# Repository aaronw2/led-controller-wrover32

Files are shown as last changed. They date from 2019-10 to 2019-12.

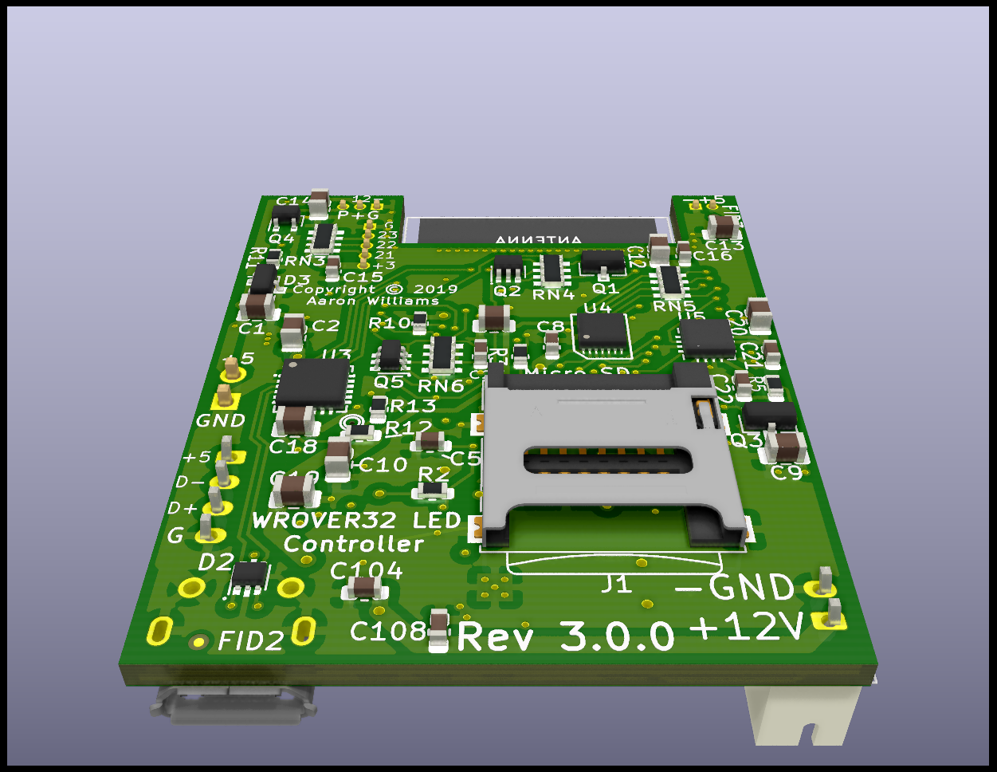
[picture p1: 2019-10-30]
led-controller-wrover32/Pictures/Back-angle.png

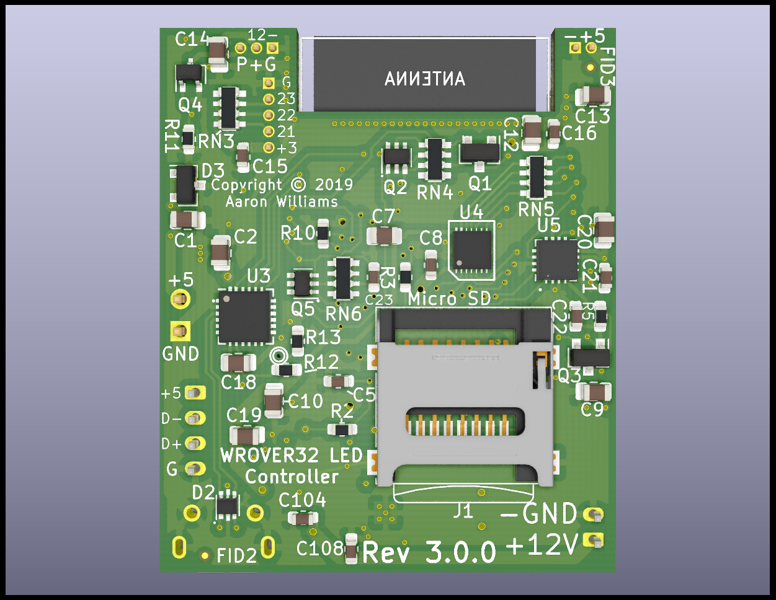
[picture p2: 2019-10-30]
led-controller-wrover32/Pictures/Back.png

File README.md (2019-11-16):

# led-controller-wrover32
Wrover32 based LED controller for NeoPixels and DotStars with 5v signalling
and micro SD

Power:

This board is powered by 5V and generates a 3.3V supply via U1.  This board
may draw up to 500ma of current at 5V.  The 3.3V supply is capable of
generating up to 1A.

This board makes use of a Torex Semiconductor XCL220 micro DC/DC converter
to efficiently provide 3.3v of power.  This inexpensive device is reportedly
93% efficient which should increase battery life and reduce heat buildup.

Do not draw more than 500ma from any single power or ground pin on J2 or J4.

On J5, VBUS is 5V as are pins 9 and 12 on J4 and pin 1 on J2.
J6 and J7 also provide +5V at the + terminal.

5V may be shunted through the board, but limit the current to no more than 2A.

5V may be supplied by any pin, however power provided by the micro SD
connector J3 should be limited to 500 ma.

USB:

There are two USB connectors on the board for programming.  The Micro USB
connector J3 or J5 may be used.  Do not use both connectors.  J5 is designed
so either a 4 pin header or a USB cable can be soldered to the board,
eliminating the need to use micro USB.

The USB port is connected to a SI Labs CP2102 USB to serial UART for
programming and debugging purposes.

I/O:

Unlike most if not all other ESP32 based boards, this board includes a
3V to 5V bidirectional level shifter for IO25, IO26, IO32 and IO33.  These
I/O ports can also be driven by the RTC in the ESP32 to help offload driving
NeoPixels.

I/O27 is connected to an on-board SK6812MINI RGB NeoPixel with the output
connected to J2 pin 4.

Connectors:

J1: Micro SD connector

J2:
1 - VBUS (+5V)
2 - GND
3 - +3.3V
4 - DO - Output from on-board NeoPixel
5 - IO34
6 - IO33_H - IO33 at 5v signalling
7 - IO32_H - IO32 at 5V signalling
8 - IO18_H - IO18 at 5V signalling
9 - IO5_H - IO5 at 5V signalling
10 - SENSOR_VN - Input to Sensor_VN pin
11 - SENSOR_VP - Input to Sensor_VP pin
12 - Reset

J3: Micro USB connector

J4:
1 - IO23 (10K pullup)
2 - IO22 (10K pullup)
3 - IO21 (10K pullup)
4 - IO19
5 - IO26
6 - IO25
7 - IO35
8 - IO0
9 - +3.3V
10 - GND
11 - GND
12 - VBUS (+5V)

J5: USB
1 - VBUS (+5) (3A input capable)
2 - D-
3 - D+
4 - GND

J6:
1 - GND
2 - VBUS (+5V)

J7:
1 - GND
2 - VBUS (+5V)
3 - FET connected to ground, driven by IO26 (max 1A, 12V)

J8:
1 - GND
2 - IO23 (pullup) same as J4-1
3 - IO22 (pullup) same as J4-2
4 - IO21 (pullup) same as J4-3
5 - +3.3V

J9:
1 - GND
2 - +5V (3A input capable)

J11:
1 - Speaker +
2 - Speaker -

J101:
Note: pins 1 and 2 are the opposite of other power connectors
1 - +12V 400ma
2 - GND

I2C:
I2C is supported on pins IO21, IO22 and IO23, though one of those pins can
also be used for a shared interruput line.

Notes:
Some pins serve multiple purposes.  For example, two of the 5V I/O pins are
shared.  For example, IO5 is also connected to the FET for PWM and IO33 is
also connected to the BCLK on the amplifier.  If these are used, do not use
the 5V I/Os for IO5 and/or IO33.  If IO33 is used, do not hook up a speaker.

IO18 and IO32 are dedicated for 5V I/O and IO27 is dedicated for the status
LED and the output of that is useable for driving WS2812s or compatible 24-bit
LEDs.

Power:

This board uses a Torex Semiconductor XCL220 buck converter to efficiently
generate 3.3v with an output capability of up to 1A.  It supports automatic
shutdown for thermal, overcurrent and under voltage events.

Any VBUS (+5V) pin many be used to deliver or draw 5V from the board.  Total
current should not exceed 2A for all combined ground and +5V pins, however
for power input connectors J5 and J9 are capable of handling 3A in order to
supply the 12V booster

Ground:
Any GND pin can be used for ground.

+3.3V
The on-board power supply is capable of generating up to 1A.  The Wrover32 can
consume up to 500ma.  Please limit power consumption to no more than 200ma to
be safe.

+12V
This board includes a 5V to 12V boost circuit in order to provide power to
a fan or other accessories via J101.  Do not exceed 400ma.  All components
needed for the 12V boost circuit start at reference 100.  To disable 12V
support, do not install any components in this range, i.e. J101, R101, etc.

RESET:

This board can be reset in one of three ways.  The serial UART, SW1 and J2
pin 12 can all be used to reset the board.  To reset the board using J2,
pull the RESET line to ground.

5V logic

This board is designed to be able to drive 5 channels of NeoPixels, or two
channels of DotStars and one channel of NeoPixels.  One NeoPixel (D1) is
built-in to the board and the output is connected to J2 pin 4.  The other
four channels are pins J2 6, 7, 8 and 9.  Note that D1 uses a WS2813B-Mini.

Connectors J2 and J4:

Connectors J2 and J4 and JST VM12B-SRSS-TB connectors and mate with the
JST 12SR-3S connector.  These connectors can be found at Digikey, including
connectors with wires already installed. Note that the wire for the mating
connectors is a bit hard to find. Alpha Wire 2928 WH005 fits this connector.
It is a bit pricy. Mouser has it cheaper than Digikey for $35/100 feet,
though I also found it online for $25. The connector requires 7 strand wire
with an outer diameter between 0.54 and 0.58mm.

Connectors J5 and J101 are JST PH series connectors which are readily
available. J101 is not at all uncommon for computer fans.

All other connectors are pin headers with 1.27mm pitch, which is half the
normal 2.54mm pitch except for J9, which uses the 2.54mm pitch.

USB:
Use either a micro USB cable OR J5, do not use both for USB I/O.  Both,
however, are safe for power and ground, however do not exceed 900ma
when using a micro USB cable.

Microphone:

An optional SPH0645LM4H-B i2s compatible microphone is available.
If present, it is configured for the left channel.  Word-select is on IO5,
clock is on IO0 and data is on IO35.

Fan control:
The PWM pin is not near the 12v supply due to routing issues.  In order to
use PWM support, the fan must be connected to +12 or +5 and the PWM pin
(J7 pin 3) for ground. Note that J7 pin 3 should never be shorted to ground
as this will cause Q4 to act as a diode and likely burn up.

Booting and programming:
This follows the model used on the Wrover development board where DTR and
RTS are used to control IO0, IO2 and RESET.  Note that revision 1.5 and later
fixes the programming by supporting IO2.  IO2 is new for the Wrover32 and is
not used by the Wroom32.

GPIOs:
IO0: I2S-BCLK, RTS for programming, J4-8
IO2: SD-DAT0, RTS for programming
IO4: SD-DAT1
IO5: 5V I/O, FAN PWM
IO12: SD-DAT2
IO13: SD-DAT3/CD
IO14: SD-Clock
IO15: SD-Command
IO16: do not use
IO17: do not use
IO18: 5V I/O
IO19: mic I2S-WS, JU4-4
IO21: Pull-up, J4-3, SDA
IO22: Pull-up, J4-2, SCL
IO23: Pull-up, J4-1, /INT
IO25: J4-6, Speaker DIN
IO26: J4-5, Speaker BCLK
IO27: Status RGB LED output
IO32: 5V I/O
IO33: 5V I/O, Speaker LRCLK
IO34: J2-5 (input only)
IO35: MIC I2S-data in, J4-7
SENSOR_VP: J2-11
SENSOR_VN: J2-10

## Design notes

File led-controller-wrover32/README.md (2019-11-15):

ESP32-Wrover I/Os

IO0: (reset/program), J4-8, MIC-BCLK
IO2: (reset/program), SD DAT0
IO4: SD DAT1
IO5: +5V I/O, FAN PWM
IO12: SD DAT2
IO13: SD DAT3/CD
IO14: SD CLK
IO15: SD CMD
IO16: DNC
IO17: DNC
IO18: +5V I/O
IO19: J4-4, MIC WS
IO21: I2C/INT, J4-3
IO22: I2C/INT, J4-2
IO23: I2C/INT, J4-1
IO25: J4-6, SPKR-DIN
IO26: J4-5, SPKR-BCLK
IO27: NeoPixel
IO32: +5V
IO33: +5V, SPKR-LRCLK
IO34: (input only) J2-5
IO35: (input only) J4-7, MIC-OUT
SENSOR_VP: J2-11
SENSOR_VN: J2-10
RXD0:
TXD0:
EN:

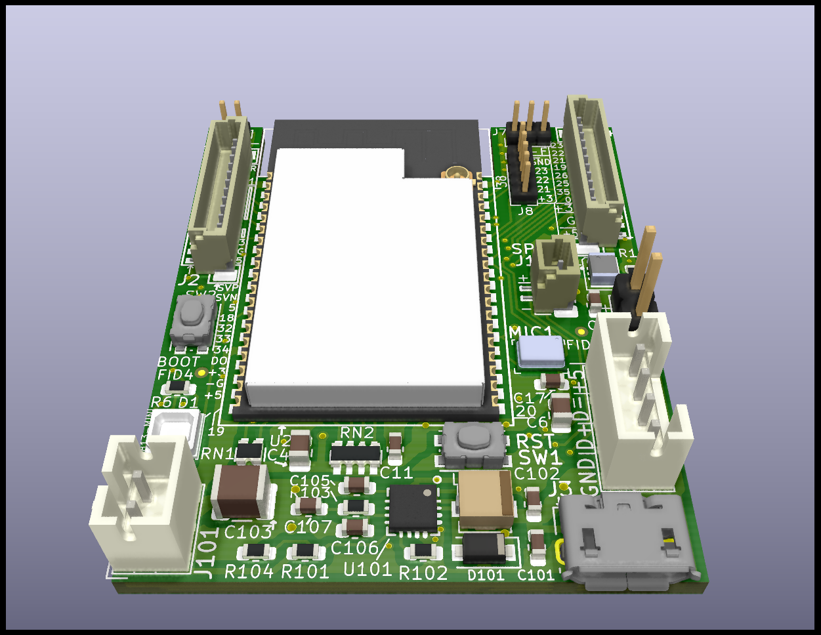
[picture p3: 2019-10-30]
led-controller-wrover32/Pictures/Front-angle.png

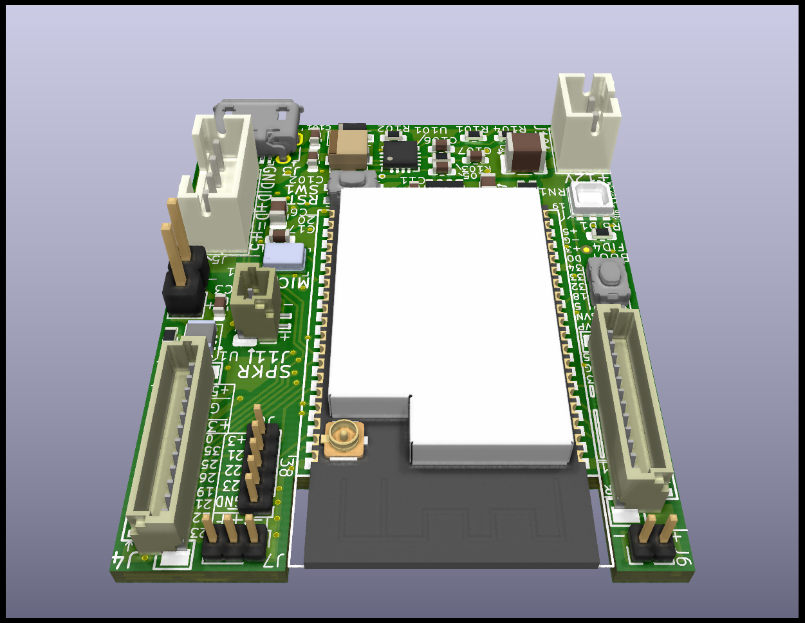
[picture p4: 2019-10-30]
led-controller-wrover32/Pictures/Front-angle-2.png

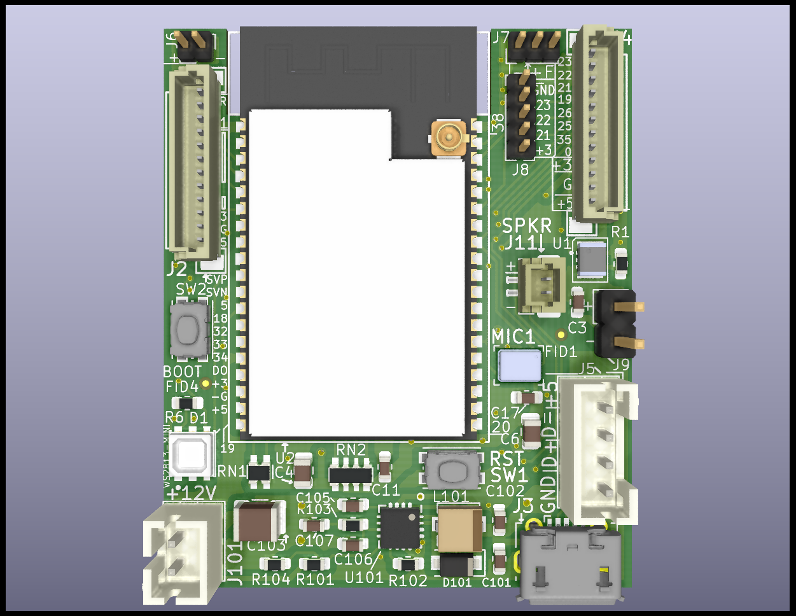
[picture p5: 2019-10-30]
led-controller-wrover32/Pictures/Front.png

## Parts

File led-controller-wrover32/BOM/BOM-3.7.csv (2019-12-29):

Refs | Value | Footprint | Quantity | DESC | MFR | MPN | SPR | SPN | SPURL
J11 | Conn_01x02 | Aaron:JST_SH_BM02B-SRSS-TB_1x02-1MP_P1.00mm_Vertical | 1 | CONN HEADER SMD 2POS 1MM | JST Sales America Inc. | BM02B-SRSS-TB(LF)(SN) | Digikey | 455-1788-1-ND | https://www.digikey.com/product-detail/en/jst-sales-america-inc/BM02B-SRSS-TB-LF-SN/455-1788-1-ND/926859
L101 | 3.3uH | Aaron:L_Vishay_IHLP-1212 | 1 | FIXED IND 3.3UH 2.7A 61 MOHM SMD | Vishay Dale | IHLP1212BZER3R3M11 | Digikey | 541-2567-1-ND | -
U101 | TPS55340-Q1 | Aaron:QFN-16-1EP_3x3mm_P0.5mm_EP2.7x2.7mm_ThermalVias | 1 | IC REG BOOST ADJ 5.25A 16WQFN | Texas Instruments | TPS55340RTER | Digikey | 296-37677-1-ND | -
MIC1 | SPH0645LM4H-B | Aaron:SPH0645LM4H-B | 1 | CRAWFORD MIC DGT I2S BOTTOM PORT | Knowles | SPH0645LM4H-B | Digikey | 423-1405-1-ND | https://www.digikey.com/products/en/audio-products/microphones/158?k=SPH0645LM4H-B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
SW2;SW1 | SW_SPST_KMR2 | Aaron:SW_SPST_KMR2 | 2 | SWITCH TACTILE SPST-NO 0.05A 32V | C&K | KMR211GLFS | Digikey | 401-1426-1-ND | https://www.digikey.com/product-detail/en/c-k/KMR211GLFS/401-1426-1-ND/550461
U4 | MAX3379EETD | Aaron:TDFN-14_3x3mm_P0.4mm_EP1.78x2.35mm | 1 | Translation - Voltage Levels 15kV ESD-Protected, 1 A, 16Mbps, Dual/Quad Low-Voltage Level Translators in UCSP | Maxim Integrated | MAX3379EETD+ | Mouser | 700-MAX3379EETD+ | https://www.mouser.com/ProductDetail/Maxim-Integrated/MAX3379EETD%2b
J3 | USB_B_Micro | Aaron:USB_Micro-B_Molex-105017-0001 | 1 | CONN RCPT USB2.0 MICRO B SMD R/A | Molex | 1050170001 | Digikey | WM1399CT-ND | -
U5 | MAX98357A | Aaron:VQFN-16-1EP_3x3mm_P0.5mm_EP1.68x1.68mm | 1 | IC AMP CLASS D MONO 3.2W 16TQFN | Maxim Integrated | MAX98357AETE+T | Digikey | MAX98357AETE+TCT-ND | https://www.digikey.com/products/en/integrated-circuits-ics/linear-amplifiers-audio/742?k=MAX98357A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
J1 | Micro_SD_Card | Aaron:microSD_HC_Wuerth_693072010801 | 1 | CONN MICRO SD CARD HINGED TYPE | Wuerth | 693072010801 | Digikey | 732-3820-1-ND | https://www.digikey.com/product-detail/en/w-rth-elektronik/693072010801/732-3820-1-ND/3124605
C16;C17;C108;C102;C21;C22;C5;C24;C8 | 0.1uF | Capacitor_SMD:C_0603_1608Metric | 9 | CAP CER 0.1UF 50V X7R 0603 | Murata Electronics | GCM188R71H104KA57D | Digikey | 490-4779-1-ND | https://www.digikey.com/product-detail/en/murata-electronics/GCM188R71H104KA57D/490-4779-1-ND/1641698
C3;C11;C15;C104 | 1uF | Capacitor_SMD:C_0603_1608Metric | 4 | CAP CER 1UF 10V X7R 0603 | Samsung | CL10B105KP8NNNC | Digikey | 1276-1946-1-ND | -
C105;C23 | 22nF | Capacitor_SMD:C_0603_1608Metric | 2 | CAP CER 0.022UF 50V X7R 0603 | Yageo | CC0603JRX7R9BB223 | Digikey | 311-4010-1-ND | https://www.digikey.com/product-detail/en/yageo/CC0603JRX7R9BB223/311-4010-1-ND/8025099
C101 | 22uF | Capacitor_SMD:C_0603_1608Metric | 1 | CAP CER 22UF 16V X5R 0603 | Samsung Electro-Mechanics | CL10A226MO7JZNC | Digikey | 1276-7076-1-ND | https://www.digikey.com/products/en/capacitors/ceramic-capacitors/60?k=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
C107 | 47nF | Capacitor_SMD:C_0603_1608Metric | 1 | CAP CER 0.47UF 50V X5R 0603 | Murata | GRM188R61H474KA12D | Digikey | 490-11994-1-ND | -
C106 | 820pF | Capacitor_SMD:C_0603_1608Metric | 1 | CAP CER 820PF 50V C0G/NPO 0603 | Yageo | CC0603JRNPO9BN821 | Digikey | 311-1775-1-ND | https://www.digikey.com/products/en?keywords=311-1775-1-ND
C1;C2;C6;C4;C10;C13;C14;C19;C9;C18;C20;C7 | 10uF | Capacitor_SMD:C_0805_2012Metric | 12 | CAP CER 10UF 16V X7R 0805 | Samsung | CL21B106KOQNNNE | Digikey | 1276-2872-1-ND | -
C12 | 22uF | Capacitor_SMD:C_0805_2012Metric | 1 | CAP CER 22UF 10V X5R 0805 | Samsung | CL21A226KPCLRNC | Digikey | 1276-6786-1-ND | https://www.digikey.com/product-detail/en/samsung-electro-mechanics/CL21A226KPCLRNC/1276-6786-1-ND/5961645
C103 | 47uF | Capacitor_SMD:C_1210_3225Metric | 1 | CAP CER 47UF 16V X5R 1210 | Samsung | CL32A476KOJNNNE | Digikey | 1276-3376-1-ND | https://www.digikey.com/product-detail/en/samsung-electro-mechanics/CL32A476KOJNNNE/1276-3376-1-ND/3891462
J101 | Conn_01x02 | Connector_JST:JST_PH_B2B-PH-K_1x02_P2.00mm_Vertical | 1 | CONN HEADER VERT 2POS 2MM | JST | B2B-PH-K-S(LF)(SN) | Digikey | 455-1704-ND | https://www.digikey.com/product-detail/en/jst-sales-america-inc/B2B-PH-K-S-LF-SN/455-1704-ND/926611
J5 | Conn_01x04 | Connector_JST:JST_PH_B4B-PH-K_1x04_P2.00mm_Vertical | 1 | CONN HEADER VERT 4POS 2MM | JST Sales America | B4B-PH-K-S(LF)(SN) | Digikey | 455-1706-ND | -
J4;J2 | BM12B-SRSS-TBT(LF)(SN) | Connectors_JST-BM12B-SURS-TF:BM12B-SRSS-TB | 2 | CONN HEADER SMD 12POS 1MM | JST | BM12B-SRSS-TBT(LF)(SN) | Digikey | 455-2960-1-ND | https://www.digikey.com/products/en/connectors-interconnects/rectangular-connectors-headers-male-pins/314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
D101 | D_Schottky | Diode_SMD:D_SOD-123F | 1 | DIODE SCHOTTKY 40V 2A SOD123F | ON | SS24FL | Digikey | SS24FLCT-ND | -
U2 | ESP32-WROVER | ESP32:ESP32-WROOVER | 1 | WIFI MODULE 128MBITS SPI FLASH | Espressif Systems | ESP32-WROVER (16MB) | Digikey | 1904-1015-1-ND | https://www.digikey.com/product-detail/en/espressif-systems/ESP32-WROVER-16MB/1904-1015-1-ND/9381724
D1 | WS2813-MINI | LED_WS2813-mini:LED_WS2813-MINI-2 | 1 | RGB 620~625nm Red, 515~525nm Green, 465~475nm Blue SMD-6 Light Emitting Diodes (LED) RoHS | World Semi | WS2813B-Mini | LCSC | C189639 | https://lcsc.com/product-detail/Light-Emitting-Diodes-LED_Worldsemi-WS2813-Mini-WS2813-3535_C189639.html
U3 | CP2104 | Package_DFN_QFN:QFN-24-1EP_4x4mm_P0.5mm_EP2.6x2.6mm | 1 | IC SGL USB-TO-UART BRIDGE 24QFN | Silicon Labs | CP2104-F03-GMR | Digikey | 336-4146-1-ND | https://www.digikey.com/products/en/integrated-circuits-ics/interface-controllers/753?k=cp2104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
Q3 | BSS138 | Package_TO_SOT_SMD:SOT-23 | 1 | N-Channel 50V 220mA (Ta) 360mW (Ta) Surface Mount SOT-23-3 | ON Semiconductor | BSS138 | Digikey | BSS138CT-ND | -
Q1 | MMSS8050-H-TP | Package_TO_SOT_SMD:SOT-23 | 1 | TRANS NPN 25V 1.5A SOT23 | Micro Commercial Co | MMSS8050-H-TP | Digikey | MMSS8050-H-TPMSCT-ND | https://www.digikey.com/products/en/discrete-semiconductor-products/transistors-bipolar-bjt-single/276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
Q2 | FMB2222A | Package_TO_SOT_SMD:SOT-23-6 | 1 | TRANS 2NPN 40V 0.5A 6SSOT | ON Semiconductor | FMB2222A | Digikey | FMB2222ACT-ND | -
Q5 | BSS138DW-7-F | Package_TO_SOT_SMD:SOT-363_SC-70-6 | 1 | MOSFET 2N-CH 50V 0.2A SC70-6 | Diodes Incorporated | BSS138DW-7-F | Digikey | BSS138DW-FDICT-ND | https://www.digikey.com/products/en/discrete-semiconductor-products/transistors-fets-mosfets-arrays/289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
D2 | USBLC6-2P6 | Package_TO_SOT_SMD:SOT-666 | 1 | TVS DIODE 5.25V 17V SOT666 | ST Microelectronics | USBLC6-2P6 | Digikey | 497-5026-1-ND | -
R103 | 1.62K | Resistor_SMD:R_0603_1608Metric | 1 | RES SMD 1.62K OHM 1% 1/10W 0603 | Yageo | RC0603FR-071K62L | Digikey | 311-1.62KHRCT-ND | https://www.digikey.com/product-detail/en/yageo/RC0603FR-071K62L/311-1.62KHRCT-ND/729816
R10 | 100K | Resistor_SMD:R_0603_1608Metric | 1 | RES SMD 100K OHM 5% 1/10W 0603 | Vishay Dale | CRCW0603100KJNEA | Digikey | 541-100KGCT-ND | -
R1;R104;R3 | 10K | Resistor_SMD:R_0603_1608Metric | 3 | RES SMD 10K OHM 1% 1/10W 0603 | Vishay Dale | CRCW060310K0FKEC | Digikey | 541-2979-1-ND | -
R102 | 18.7K | Resistor_SMD:R_0603_1608Metric | 1 | RES SMD 18.7K OHM 1% 1/10W 0603 | Yageo | RC0603FR-0718K7L | Digikey | 311-18.7KHRCT-ND | https://www.digikey.com/product-detail/en/yageo/RC0603FR-0718K7L/311-18.7KHRCT-ND/729940
R5;R6 | 4.7K | Resistor_SMD:R_0603_1608Metric | 2 | RES SMD 4.7K OHM 1% 1/10W 0603 | Bourns Inc. | CR0603-FX-4701ELF | Digikey | CR0603-FX-4701ELFCT-ND | https://www.digikey.com/product-detail/en/bourns-inc/CR0603-FX-4701ELF/CR0603-FX-4701ELFCT-ND/3740884
R2 | 470 | Resistor_SMD:R_0603_1608Metric | 1 | RES SMD 470 OHM 1% 1/10W 0603 | Samsung | RC1608F471CS | Digikey | 1276-4619-1-ND | -
R101 | 86.6K | Resistor_SMD:R_0603_1608Metric | 1 | RES SMD 86.6K OHM 1% 1/10W 0603 | Vishay Dale | CRCW060386K6FKEA | Digikey | 541-86.6KHCT-ND | -
RN1 | 10K | Resistor_SMD:R_Array_Convex_2x0603 | 1 | 10k Ohm +/- 5% Isolated Resistor Network, 0606, Concave | Panasonic | EXB-V4V103JV | Digikey | Y2103CT-ND | -
RN4;RN6 | 100K | Resistor_SMD:R_Array_Convex_4x0603 | 2 | RES ARRAY 4 RES 100K OHM 1206 | Panasonic | EXB-V8V104JV | Digikey | Y4104CT-ND | https://www.digikey.com/product-detail/en/panasonic-electronic-components/EXB-V8V104JV/Y4104CT-ND/155183
RN2 | 10K | Resistor_SMD:R_Array_Convex_4x0603 | 1 | RES ARRAY 4 RES 10K OHM 1206 | Panasonic | EXB-V8V103JV | Digikey | Y4103CT-ND | -
RN3 | 4.7K | Resistor_SMD:R_Array_Convex_4x0603 | 1 | RES ARRAY 4 RES 4.7K OHM 1206 | Bourns Inc. | CAT16-4701F4LF | Digikey | CAT16-4701F4LFCT-ND | https://www.digikey.com/product-detail/en/bourns-inc/CAT16-4701F4LF/CAT16-4701F4LFCT-ND/3592883
U1 | XCL220 | Torex_Semi:CL-2025-02 | 1 | DC DC CONVERTER 3.3V | Torex Semiconductor | XCL220B333FR-G | Digikey | 893-1279-1-ND | -

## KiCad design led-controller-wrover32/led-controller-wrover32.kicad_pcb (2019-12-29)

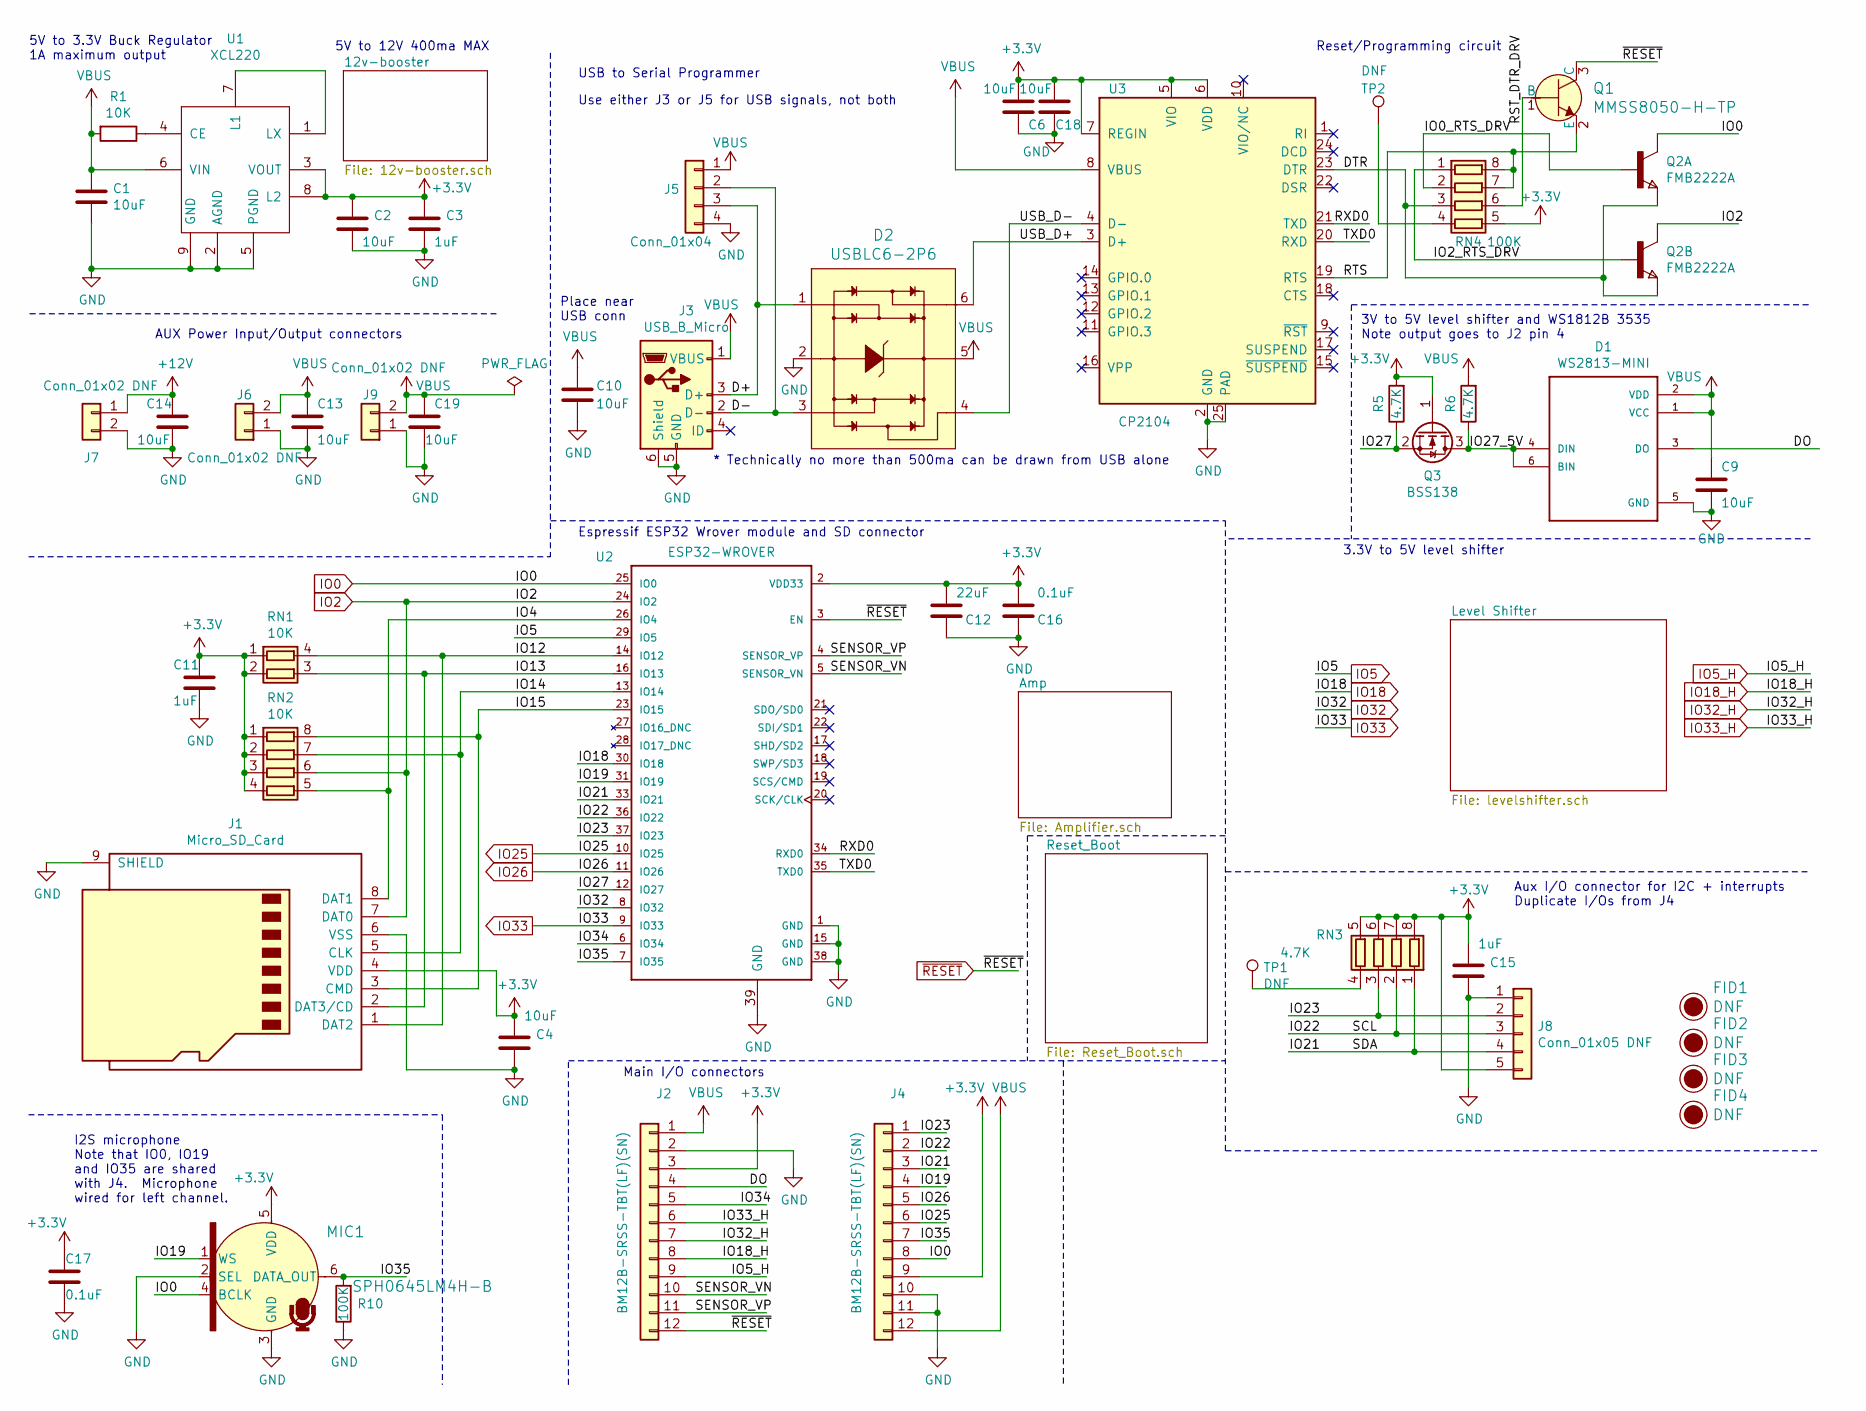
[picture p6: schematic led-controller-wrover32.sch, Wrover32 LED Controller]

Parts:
C1: 10uF; C_0805_2012Metric; Tolerance 20%; Minimum Voltage 10; MPN CL21B106KOQNNNE
C2, C4, C6, C9, C10, C13, C14, C18, C19: 10uF; C_0805_2012Metric; MPN CL21B106KOQNNNE
C3, C11, C15: 1uF; C_0603_1608Metric; MPN CL10B105KP8NNNC
C12: 22uF; C_0805_2012Metric; MPN CL21A226KPCLRNC
C16, C17: 0.1uF; C_0603_1608Metric; MPN GCM188R71H104KA57D
D1: WS2813-MINI; LED_WS2813-MINI-2; MPN WS2813B-Mini
D2: USBLC6-2P6; SOT-666; MPN USBLC6-2P6; Digi-Key_PN 497-5026-1-ND
FID1, FID2, FID3, FID4: DNF; Fiducial_0.5mm_Mask1mm
J1: Micro_SD_Card; microSD_HC_Wuerth_693072010801; MPN 693072010801
J2, J4: BM12B-SRSS-TBT(LF)(SN); BM12B-SRSS-TB; MPN BM12B-SRSS-TBT(LF)(SN)
J3: USB_B_Micro; USB_Micro-B_Molex-105017-0001; MPN 1050170001
J5: Conn_01x04; JST_PH_B4B-PH-K_1x04_P2.00mm_Vertical; MPN B4B-PH-K-S(LF)(SN)
J6, J7: Conn_01x02 DNF; PinHeader_1x02_P1.27mm_Vertical; MPN TMS-102-01-G-S
J8: Conn_01x05 DNF; PinHeader_1x05_P1.27mm_Vertical; MPN TMS-105-01-G-S
J9: Conn_01x02 DNF; PinHeader_1x02_P2.54mm_Vertical
MIC1: SPH0645LM4H-B; MPN SPH0645LM4H-B; Digi-Key_PN 423-1405-1-ND
Q1: MMSS8050-H-TP; SOT-23; MPN MMSS8050-H-TP; Digi-Key_PN MMSS8050-H-TPMSCT-ND
Q2: FMB2222A; SOT-23-6; MPN FMB2222A
Q3: BSS138; SOT-23; MPN BSS138
R1: 10K; R_0603_1608Metric; Tolerance 5%; MPN CRCW060310K0FKEC
R5, R6: 4.7K; R_0603_1608Metric; MPN CR0603-FX-4701ELF
R10: 100K; R_0603_1608Metric; MPN CRCW0603100KJNEA
RN1: 10K; R_Array_Convex_2x0603; MPN EXB-V4V103JV
RN2: 10K; R_Array_Convex_4x0603; MPN EXB-V8V103JV
RN3: 4.7K; R_Array_Convex_4x0603; MPN CAT16-4701F4LF
RN4: 100K; R_Array_Convex_4x0603; MPN EXB-V8V104JV
TP1, TP2: DNF; TestPoint_Pad_D1.0mm
U1: XCL220; CL-2025-02; MPN XCL220B333FR-G
U2: ESP32-WROVER; ESP32-WROOVER; MPN ESP32-WROVER (16MB)
U3: CP2104; QFN-24-1EP_4x4mm_P0.5mm_EP2.6x2.6mm; MPN CP2104-F03-GMR

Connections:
+3V3: C2.1, C3.1, C4.1, C6.1, C11.1, C12.1, C15.1, C16.1, C17.1, C18.1, J1.4 (VDD), J2.3, J4.9, J8.5, MIC1.5 (VDD), Q3.1 (G), R5.2, RN1.1 (R1.1), RN1.2 (R2.1), RN2.1 (R1.1), RN2.2 (R2.1), RN2.3 (R3.1), RN2.4 (R4.1), RN3.5 (R4.2), RN3.6 (R3.2), RN3.7 (R2.2), RN3.8 (R1.2), RN4.5 (R4.2), U1.3 (VOUT), U1.8 (L2), U2.2 (VDD33), U3.5 (VIO), U3.6 (VDD), U3.7 (REGIN); also elsewhere on the board
+12V: C14.1, J7.1; also elsewhere on the board
/D+: D2.1, J3.3 (D+), J5.3
/D-: D2.3, J3.2 (D-), J5.2
/DO: D1.3 (DO), J2.4
/DTR: Q2.2 (E), Q2.5 (E), RN4.3 (R3.1), U3.23 (DTR)
/IO0_RTS_DRV: Q2.1 (B), RN4.2 (R2.1)
/IO2_RTS_DRV: Q2.3 (B), RN4.1 (R1.1)
/IO4: J1.8 (DAT1), RN2.5 (R4.2), U2.26 (IO4)
/IO12: J1.1 (DAT2), RN1.4 (R1.2), U2.14 (IO12)
/IO13: J1.2 (DAT3/CD), RN1.3 (R2.2), U2.16 (IO13)
/IO14: J1.5 (CLK), RN2.7 (R2.2), U2.13 (IO14)
/IO15: J1.3 (CMD), RN2.8 (R1.2), U2.23 (IO15)
/IO19: J4.4, MIC1.1 (WS), U2.31 (IO19)
/IO21: J4.3, J8.4, RN3.1 (R1.1), U2.33 (IO21)
/IO22: J4.2, J8.3, RN3.2 (R2.1), U2.36 (IO22)
/IO23: J4.1, J8.2, RN3.3 (R3.1), U2.37 (IO23)
/IO27: Q3.2 (S), R5.1, U2.12 (IO27)
/IO27_5V: D1.4 (DIN), D1.6 (BIN), Q3.3 (D), R6.1
/IO34: J2.5, U2.6 (IO34)
/IO35: J4.7, MIC1.6 (DATA_OUT), R10.2, U2.7 (IO35)
/RST_DTR_DRV: Q1.1 (B), RN4.6 (R3.2)
/RTS: Q1.2 (E), RN4.7 (R2.2), RN4.8 (R1.2), U3.19 (RTS)
/RXD0: U2.34 (RXD0), U3.21 (TXD)
/SENSOR_VN: J2.10, U2.5 (SENSOR_VN)
/SENSOR_VP: J2.11, U2.4 (SENSOR_VP)
/TXD0: U2.35 (TXD0), U3.20 (RXD)
/USB_D+: D2.6, U3.3 (D+)
/USB_D-: D2.4, U3.4 (D-)
GND: C1.2, C2.2, C3.2, C4.2, C6.2, C9.2, C10.2, C11.2, C12.2, C13.2, C14.2, C15.2, C16.2, C17.2, C18.2, C19.2, D1.5 (GND), D2.2, J1.6 (VSS), J1.9 (SHIELD), J2.2, J3.5 (GND), J3.6 (Shield), J4.10, J4.11, J5.4, J6.1, J7.2, J8.1, J9.1, MIC1.2 (SEL), MIC1.3 (GND), R10.1, U1.2 (AGND), U1.5 (PGND), U1.9 (GND), U2.1 (GND), U2.15 (GND), U2.38 (GND), U2.39 (GND), U3.2 (GND), U3.25 (PAD); also elsewhere on the board
IO0: J4.8, MIC1.4 (BCLK), Q2.6 (C), U2.25 (IO0); also elsewhere on the board
IO2: J1.7 (DAT0), Q2.4 (C), RN2.6 (R3.2), U2.24 (IO2); also elsewhere on the board
IO5: U2.29 (IO5); also elsewhere on the board
IO5_H: J2.9; also elsewhere on the board
IO18: U2.30 (IO18); also elsewhere on the board
IO18_H: J2.8; also elsewhere on the board
IO25: J4.6, U2.10 (IO25); also elsewhere on the board
IO26: J4.5, U2.11 (IO26); also elsewhere on the board
IO32: U2.8 (IO32); also elsewhere on the board
IO32_H: J2.7; also elsewhere on the board
IO33: U2.9 (IO33); also elsewhere on the board
IO33_H: J2.6; also elsewhere on the board
unnamed: R1.1, U1.4 (CE)
unnamed: RN3.4 (R4.1), TP1.1
unnamed: RN4.4 (R4.1), TP2.1
unnamed: U1.1 (LX), U1.7 (L1)
VBUS: C1.1, C9.1, C10.1, C13.1, C19.1, D1.1 (VCC), D1.2 (VDD), D2.5, J2.1, J3.1 (VBUS), J4.12, J5.1, J6.2, J9.2, R1.2, R6.2, U1.6 (VIN), U3.8 (VBUS); also elsewhere on the board
~RESET: J2.12, Q1.3 (C), U2.3 (EN); also elsewhere on the board

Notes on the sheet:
3.3V to 5V level shifter
Place near USB conn
5V to 3.3V Buck Regulator 1A maximum output
AUX Power Input/Output connectors
USB to Serial Programmer
Use either J3 or J5 for USB signals, not both
* Technically no more than 500ma can be drawn from USB alone
Reset/Programming circuit
I2S microphone Note that IO0, IO19 and IO35 are shared with J4. Microphone wired for left channel.
Main I/O connectors
Aux I/O connector for I2C + interrupts Duplicate I/Os from J4
Espressif ESP32 Wrover module and SD connector
5V to 12V 400ma MAX
3V to 5V level shifter and WS1812B 3535 Note output goes to J2 pin 4

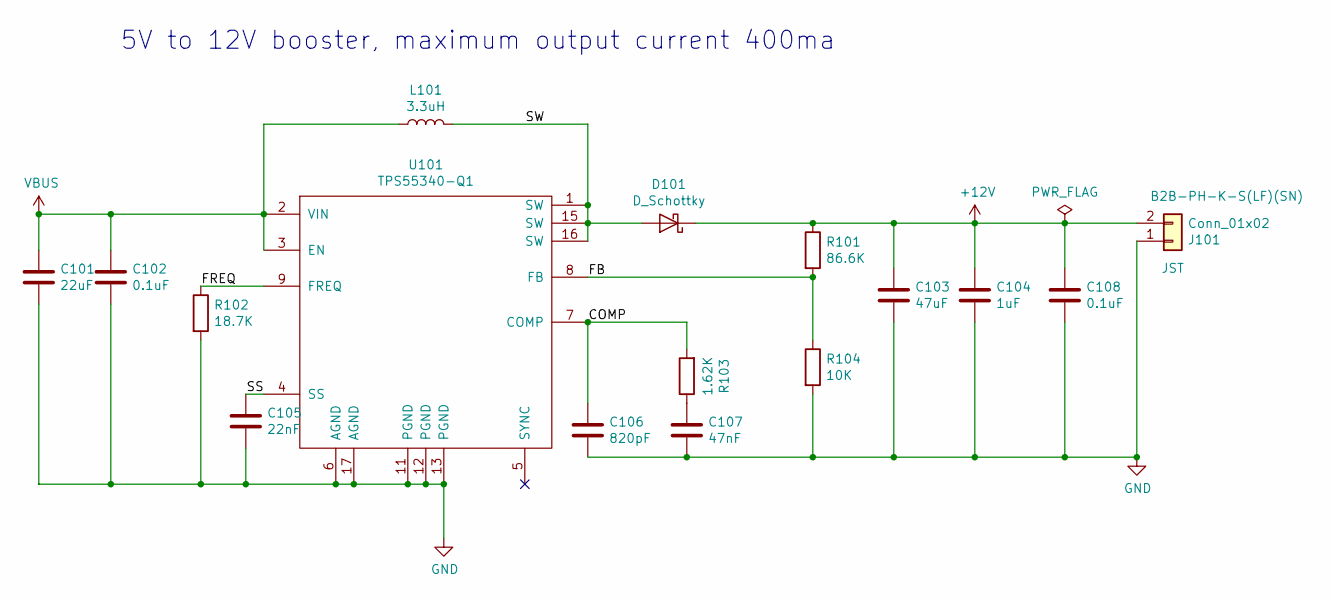
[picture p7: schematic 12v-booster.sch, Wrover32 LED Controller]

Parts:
C101: 22uF; C_0603_1608Metric; MPN CL10A226MO7JZNC
C102, C108: 0.1uF; C_0603_1608Metric; MPN GCM188R71H104KA57D
C103: 47uF; C_1210_3225Metric; MPN CL32A476KOJNNNE
C104: 1uF; C_0603_1608Metric; MPN CL10B105KP8NNNC
C105: 22nF; C_0603_1608Metric; MPN CC0603JRX7R9BB223
C106: 820pF; C_0603_1608Metric; MPN CC0603JRNPO9BN821
C107: 47nF; C_0603_1608Metric; MPN GRM188R61H474KA12D
D101: D_Schottky; D_SOD-123F; MPN SS24FL
J101: Conn_01x02; JST_PH_B2B-PH-K_1x02_P2.00mm_Vertical; MPN B2B-PH-K-S(LF)(SN)
L101: 3.3uH; L_Vishay_IHLP-1212; MPN IHLP1212BZER3R3M11
R101: 86.6K; R_0603_1608Metric; MPN CRCW060386K6FKEA
R102: 18.7K; R_0603_1608Metric; MPN RC0603FR-0718K7L
R103: 1.62K; R_0603_1608Metric; MPN RC0603FR-071K62L
R104: 10K; R_0603_1608Metric; MPN CRCW060310K0FKEC
U101: TPS55340-Q1; QFN-16-1EP_3x3mm_P0.5mm_EP2.7x2.7mm_ThermalVias; MPN TPS55340RTER

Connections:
+12V: C103.1, C104.1, C108.1, D101.1 (K), J101.2, R101.1; also elsewhere on the board
/12v-booster/COMP: C106.1, R103.2, U101.7 (COMP)
/12v-booster/FB: R101.2, R104.1, U101.8 (FB)
/12v-booster/FREQ: R102.1, U101.9 (FREQ)
/12v-booster/SS: C105.1, U101.4 (SS)
/12v-booster/SW: D101.2 (A), L101.2, U101.1 (SW), U101.15 (SW), U101.16 (SW)
GND: C101.2, C102.2, C103.2, C104.2, C105.2, C106.2, C107.2, C108.2, J101.1, R102.2, R104.2, U101.6 (AGND), U101.11 (PGND), U101.12 (PGND), U101.13 (PGND), U101.17 (AGND); also elsewhere on the board
unnamed: C107.1, R103.1
VBUS: C101.1, C102.1, L101.1, U101.2 (VIN), U101.3 (EN); also elsewhere on the board

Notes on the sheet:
5V to 12V booster, maximum output current 400ma

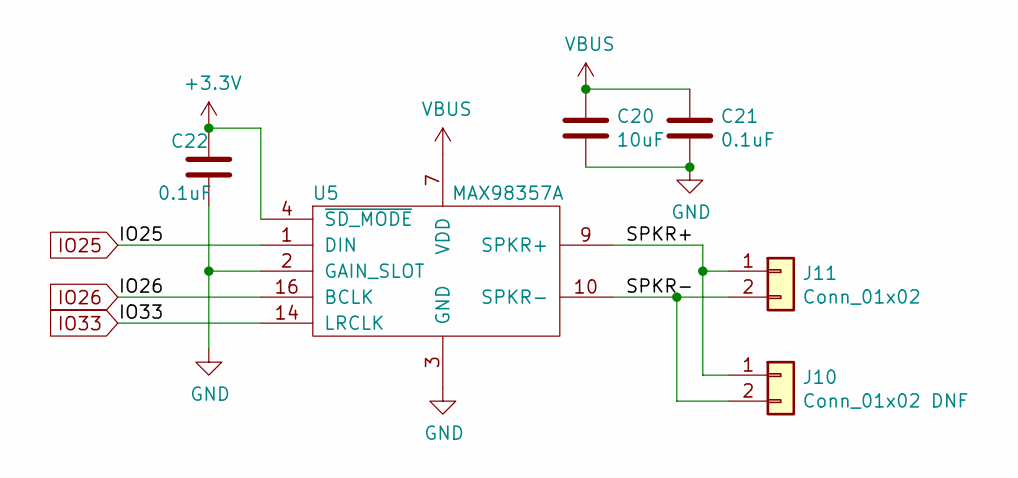
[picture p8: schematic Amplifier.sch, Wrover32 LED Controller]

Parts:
C20: 10uF; C_0805_2012Metric; MPN CL21B106KOQNNNE
C21, C22: 0.1uF; C_0603_1608Metric; MPN GCM188R71H104KA57D
J10: Conn_01x02 DNF; PinHeader_1x02_P1.27mm_Vertical_SMD_Pin1Left; MPN M50-3630242R
J11: Conn_01x02; JST_SH_BM02B-SRSS-TB_1x02-1MP_P1.00mm_Vertical; MPN BM02B-SRSS-TB(LF)(SN)
U5: MAX98357A; VQFN-16-1EP_3x3mm_P0.5mm_EP1.68x1.68mm; MPN MAX98357AETE+T

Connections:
+3V3: C22.1, U5.4 (~SD_MODE); also elsewhere on the board
/Amp/SPKR+: J10.1, J11.1, U5.9 (SPKR+)
/Amp/SPKR-: J10.2, J11.2, U5.10 (SPKR-)
GND: C20.2, C21.2, C22.2, U5.2 (GAIN_SLOT), U5.3 (GND), U5.11 (GND), U5.15 (GND), U5.17 (GND); also elsewhere on the board
IO25: U5.1 (DIN); also elsewhere on the board
IO26: U5.16 (BCLK); also elsewhere on the board
IO33: U5.14 (LRCLK); also elsewhere on the board
VBUS: C20.1, C21.1, U5.7 (VDD), U5.8 (VDD); also elsewhere on the board

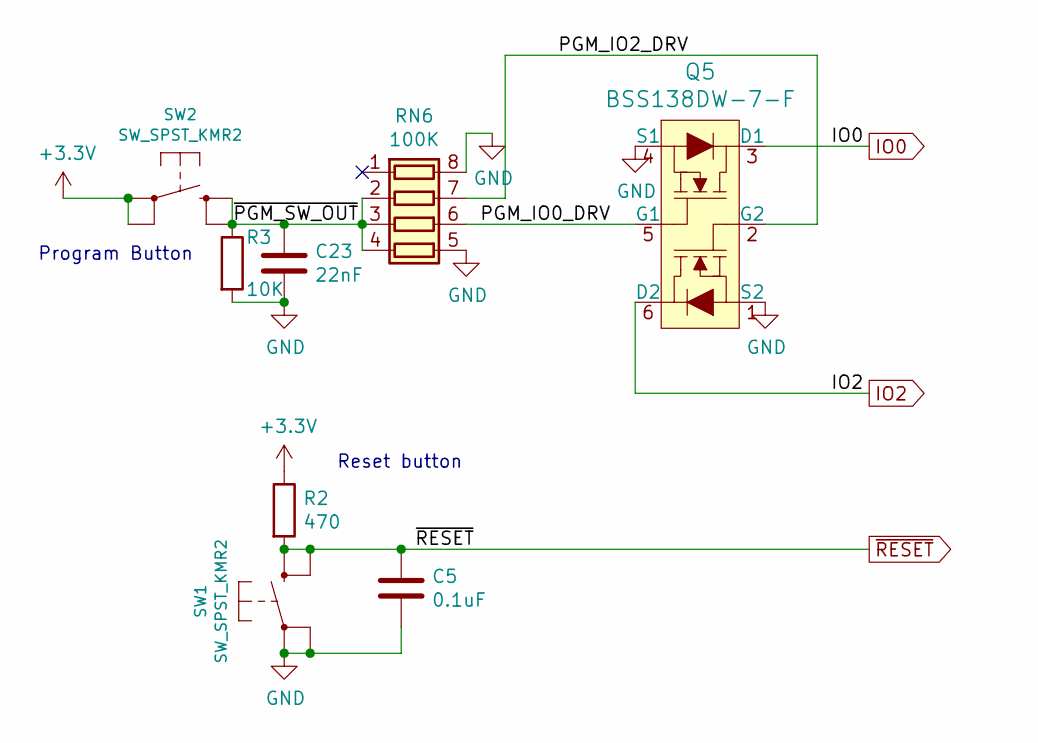
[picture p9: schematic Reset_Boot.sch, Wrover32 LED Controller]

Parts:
C5: 0.1uF; C_0603_1608Metric; MPN GCM188R71H104KA57D
C23: 22nF; C_0603_1608Metric; MPN CC0603JRX7R9BB223
Q5: BSS138DW-7-F; SOT-363_SC-70-6; MPN BSS138DW-7-F; Digi-Key_PN BSS138DW-FDICT-ND
R2: 470; R_0603_1608Metric; MPN RC1608F471CS
R3: 10K; R_0603_1608Metric; MPN CRCW060310K0FKEC
RN6: 100K; R_Array_Convex_4x0603; MPN EXB-V8V104JV
SW1, SW2: SW_SPST_KMR2; MPN KMR211GLFS

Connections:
+3V3: R2.1, SW2.1; also elsewhere on the board
/Reset_Boot/PGM_IO0_DRV: Q5.5 (G1), RN6.6 (R3.2)
/Reset_Boot/PGM_IO2_DRV: Q5.2 (G2), RN6.7 (R2.2)
/Reset_Boot/~PGM_SW_OUT: C23.1, R3.1, RN6.2 (R2.1), RN6.3 (R3.1), RN6.4 (R4.1), SW2.2 (S)
GND: C5.2, C23.2, Q5.1 (S2), Q5.4 (S1), R3.2, RN6.5 (R4.2), RN6.8 (R1.2), SW1.1; also elsewhere on the board
IO0: Q5.3 (D1); also elsewhere on the board
IO2: Q5.6 (D2); also elsewhere on the board
~RESET: C5.1, R2.2, SW1.2 (S); also elsewhere on the board

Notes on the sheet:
Reset button
Program Button

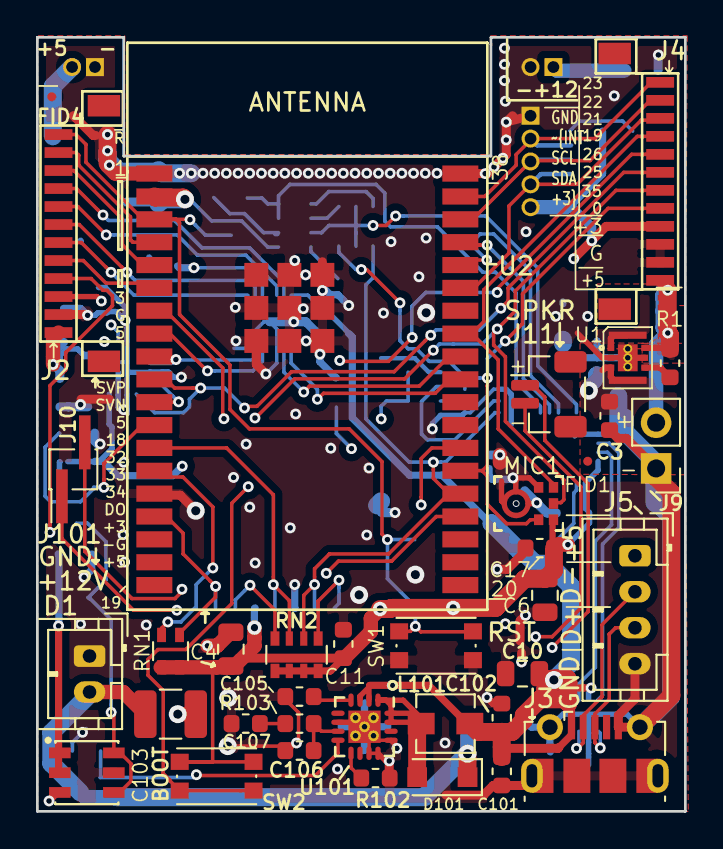
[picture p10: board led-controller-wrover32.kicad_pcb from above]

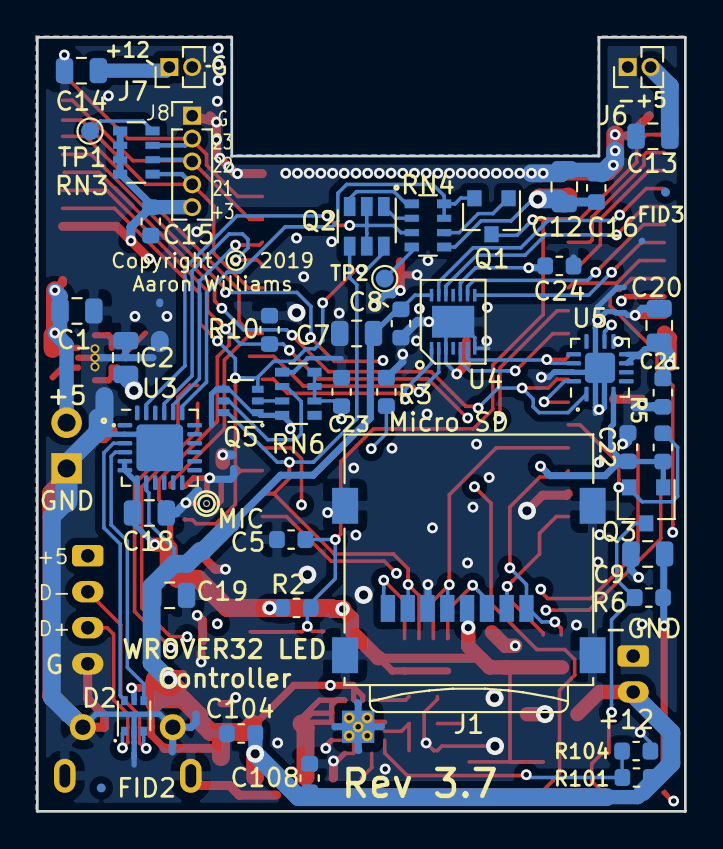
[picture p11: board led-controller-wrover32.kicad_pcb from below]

Board: 4 copper layers, 36.0 x 43.0 mm, 82 parts (46 on the bottom side), 59 nets.

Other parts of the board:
C7: 10uF; C_0805_2012Metric
C8, C24: 0.1uF; C_0603_1608Metric
U4: MAX3379EETD; TDFN-14_3x3mm_P0.4mm_EP1.78x2.35mm

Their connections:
+3V3: C24.1, U4.10; also elsewhere on the board
GND: C7.2, C8.2, C24.2, U4.3, U4.7, U4.15; also elsewhere on the board
IO5: U4.1; also elsewhere on the board
IO5_H: U4.13; also elsewhere on the board
IO18: U4.2; also elsewhere on the board
IO18_H: U4.12; also elsewhere on the board
IO32: U4.5; also elsewhere on the board
IO32_H: U4.9; also elsewhere on the board
IO33: U4.6; also elsewhere on the board
IO33_H: U4.8; also elsewhere on the board
VBUS: C7.1, C8.1, U4.14; also elsewhere on the board

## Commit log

2018-09-09 Initial checkin of Espressif Wrover32 LED controller board
    [led-controller-wrover32.kicad_pcb, led-controller-wrover32.sch]
2018-09-09 Some minor cleanup.
    - Moved power trace too close to ground pad for ESP32.
    - Fixed silkscreen for J2 and J4 and moved some references and text.
    [led-controller-wrover32.kicad_pcb]
2018-09-09 Changed page size to Letter instead of A4.
    [led-controller-wrover32.kicad_pcb, led-controller-wrover32.sch]
2018-09-10 Fixed footprint for NeoPixel.
    [led-controller-wrover32.kicad_pcb, led-controller-wrover32.sch]
2018-09-10 I updated a few more things.
    - Slightly re-arranged the connectors so 5v isn't next to 3v and 3v I/O
    - Fixed footprints for NeoPixel MINI and power supply
    - Added a power supervisor chip
    - Some routing improvements
    [led-controller-wrover32.kicad_pcb, led-controller-wrover32.sch]
2018-09-13 I changed some part numbers and fixed the solder paste for the connectors.
    [led-controller-wrover32.kicad_pcb, led-controller-wrover32.sch]
2018-09-18 Revision 1.1.1, moved things around a little.
    [led-controller-wrover32.kicad_pcb, led-controller-wrover32.sch]
2018-09-20 - Added some more I/O pins to J4 and added pull-up resistors to IO21, IO22 and IO23. - Cleaned up Torex buck converter - Minor layout changes - Added more ground vias near the antenna. - Added anothe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
    [led-controller-wrover32.kicad_pcb, led-controller-wrover32.sch]
2018-09-20 Did some more trace cleanup.
    [led-controller-wrover32.kicad_pcb, led-controller-wrover32.sch]
2018-09-20 Updated README.MD with more info
    Added more information. All info is related to version 1.2 of the board
2018-09-21 Forgot to check in this file to 1.2
    [led-controller-wrover32.kicad_pcb]
2018-09-21 Fixed some silkscreen issues.
    [led-controller-wrover32.kicad_pcb]
2018-09-21 Fixed several issues.
    1. GPIOs 16 and 17 should not be connected.
    2. GPIO 35 was mislabeled GPIO36. It's input only and would not have
    been able to drive the TS pin oin the MAX chip.
    3. Routed GPIO35 to J4.
    4. Added a 0.1uF bypass capacitor for Wrover32 like the datasheet recommends.
    5. Added another 3.3v pin to J4 after removing GPIOs 16 and 17.
    [led-controller-wrover32.kicad_pcb, led-controller-wrover32.sch]
2018-09-23 Added microphone and updated README
    [led-controller-wrover32.kicad_pcb, led-controller-wrover32.sch]
2018-09-23 Changed the connectors from JST to a TE 1-1734595-2 connector.
    This connector uses crimped on pins, but it may be easier to deal
    with since it works with 28 gauge wire whereas the JST requires 30
    gauge (though I ordered some 28AWG that should fit it).
    This can always be reverted.
    [led-controller-wrover32.kicad_pcb, led-controller-wrover32.sch]
2018-10-04 Finalized v1.4 design.
    Added USB protection diodes.
    Cleaned up routing some more.
    Cleaned up the silk screening after getting connector models.
    [led-controller-wrover32.kicad_pcb, led-controller-wrover32.sch]
2018-10-11 Minor cleanup. - Removed overlapping fiducials (which aren't really needed) - Changed 3 pull-up resistors for IO21, IO22 and IO23 to use a resistor network and moved further away from J8 - Fixed unco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
    [led-controller-wrover32.kicad_pcb, led-controller-wrover32.sch]
2018-10-11 Fixed solder mask clearance.
    [led-controller-wrover32.kicad_pcb, led-controller-wrover32.sch]
2018-10-14 - Cleaned up the schematic - Made J5 USB D+ and D- go through protection diodes
    [led-controller-wrover32.kicad_pcb, led-controller-wrover32.sch]
2018-11-06 Fixed (hopefully) the ws1812b 3535 footprint.
    [led-controller-wrover32.kicad_pcb, led-controller-wrover32.sch]
2018-11-10 This fixes a number of issues: - IO2 is now set according to the DTR and RTS signals. This is required for booting over the serial port. - Some more footprints were found to be using the old Kicad 4 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
    [led-controller-wrover32.kicad_pcb, led-controller-wrover32.sch]
2018-11-10 Added 12v boost supply and enlarged board.
    This branch and initial commit enlarges the board in order to add a 5V to
    12V boost switching supply which can provide up to 400ma of current.
    Additionally, J5 was changed to a JST PH connector and J9 and J101 were
    added. All 12V boost supply components start at 100. Due to the
    addition of the boost switching supply, the length of the board was
    increased.
    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
    [12v-booster.sch, led-controller-wrover32.kicad_pcb, led-controller-wrover32.sch]
2018-11-10 Added BOM and also fixed missing value for RN3
    [12v-booster.sch, bom.csv, led-controller-wrover32.kicad_pcb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]
2019-01-26 Fixed solder mask padding.
    [12v-booster.sch, led-controller-wrover32.kicad_pcb, led-controller-wrover32.sch]
2019-01-26 Oops, changed the wrong thing, this fixes it.
    [led-controller-wrover32.kicad_pcb]
2019-05-23 2.1.0: Changed NeoPixel to WS2813B-Mini
    This replaces the SK6812-3535 with a WS2813B-Mini. The mini is able to
    dissipate heat better.
    Also upgraded KiCad to 5.1.2.
    Added teardrops to vias.
    BOM updated with J5 fixed.
    NOTE: The WS2813B-Mini footprint has not yet been tested. This is a custom
    footprint to try and fit the "unique" pattern of the pads.
    [12v-booster.sch, Audio.sch, bom.csv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]
2019-10-30 Version 3.0.0
    - Added speaker output support
    - Added 22 ohm resistors on 5V I/O
    - Changed from 2 to 4 layers
    - Added boot button
    - Added 12V to PWM output
    - Added 5V protection diode
    [12v-booster.sch, bom.csv, led-controller-wrover32.kicad_pcb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]
2019-10-30 Updated to version 3.0.0
    - Added boot button for programming
    - Added speaker output
    - Added protection diode for 5V
    - Fixed USB program and reset circuit to match development board
    - Made board 4 layers
    - Changed voltage at PWM output from 5V to 12V
    [Amplifier.sch, BOM.csv, Reset_Boot.sch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]
2019-11-15 Fixed microphone, fan PWM and speaker
    The ground was not hooked up to the microphone due to an issue with the
    footprint.
    The PWM pin was also used by the microphone. Moved PWM pin to IO 5 which is
    also shared with 5V output.
    The speaker LR clock was using IO34 which is input only. Moved to IO33 which
    is also shared with a 5V output.
    Updated revision to 3.0.1.
    Fixed page settings, updated dates and revisions.
    [Amplifier.sch, led-controller-wrover32.kicad_pcb, led-controller-wrover32.sch]
2019-11-16 Minor cleanup
    [led-controller-wrover32.kicad_pcb, led-controller-wrover32.sch]
2019-11-16 Fixed serial interface, TX and RX were swapped
    Added additional ground around the antenna to the power plane
    Minor cleanups
    [led-controller-wrover32.kicad_pcb, led-controller-wrover32.sch]
2019-11-16 Minor changes.
    [12v-booster.sch, Amplifier.sch, BOM.csv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]
2019-11-16 Minor fixup for filled areas.
    [led-controller-wrover32.kicad_pcb]
2019-11-16 Fix the microphone footprint and other minor cleanup. Note that this updates the stencil but the old stencil should still work without issues.
    Rev 3.0.4
    [12v-booster.sch, Amplifier.sch, Reset_Boot.sch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]
2019-11-23 Changed output 5V driver
    [12v-booster.sch, Amplifier.sch, Reset_Boot.sch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]
2019-12-20 Fix reset circuit and other stuff
    This fixes the reset circuit and moves a few components. It also
    cleans up the BOM a bit.
    Also bumped to version 3.5.0
    [12v-booster.sch, Amplifier.sch, BOM.csv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]
2019-12-21 Fixed solder mask settings
    [led-controller-wrover32.kicad_pcb]
2019-12-21 Fixed unconnected trace and more solder mask adjustments.
    [led-controller-wrover32.kicad_pcb]
2019-12-25 Moved WS2813B after fixing footprint v3.6
    [12v-booster.sch, Amplifier.sch, BOM.csv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]
2019-12-27 Changed UART to CP2104 to simplify.
    [12v-booster.sch, Amplifier.sch, Reset_Boot.sch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]
2019-12-29 Minor changes
    - Tweaked some of the component values in the 12V supply as per TI.
    - Removed unnecessary protection diode, the USB one is enough.
    - Changed UART to CS2104 which eliminates two resistors and is
    slightly cheaper
    - Updated PCB to reflect changes.
    [12v-booster.sch, Amplifier.sch, BOM-3.7.csv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]

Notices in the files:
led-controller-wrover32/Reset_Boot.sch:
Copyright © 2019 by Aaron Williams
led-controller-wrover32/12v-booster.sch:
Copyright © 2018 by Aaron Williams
